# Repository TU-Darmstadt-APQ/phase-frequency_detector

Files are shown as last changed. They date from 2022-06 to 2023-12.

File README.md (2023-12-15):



Phase-Frequency Detector
=====================
This repository contains the [KiCad](https://www.kicad.org/) design files of a phase-frequency detector designed for application in optical phase-locked loops (OPLL). The detector compares a beat-note signal with a reference signal and creates an output signal proportional to the phase deviation of the beat-note from the reference. Optionally, the beat-note input can be equipped with a divider (default: 4) for a larger input-frequency range.  The module also comprises a fast analog proportional-derivative controller for high-bandwidth feedback. 

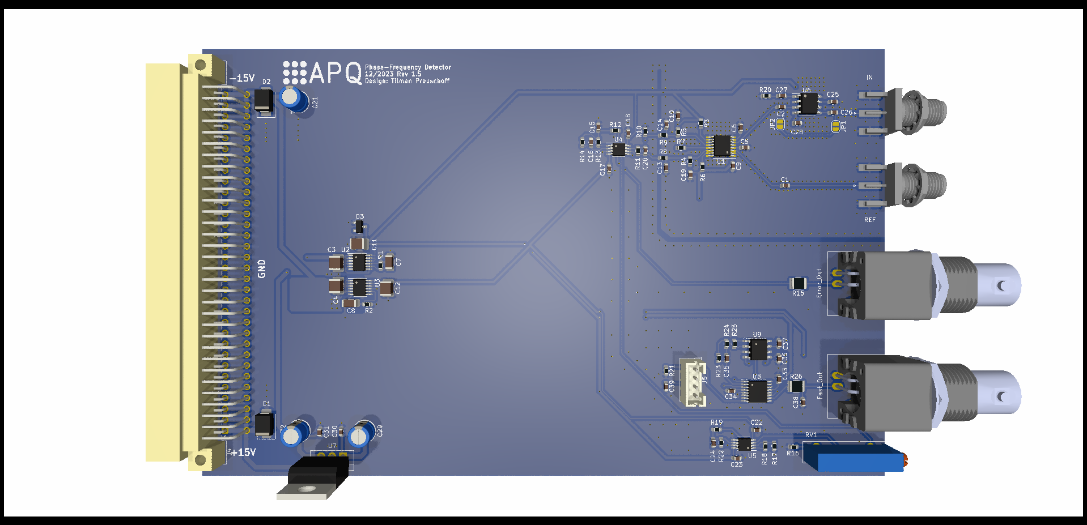
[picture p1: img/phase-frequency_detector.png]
PCB image


**Features**

- Input frequency range
  - 10 MHz to 1.3 GHz without divider
  - 500 MHz to 5.2 GHz with divider (HMC365)
- Input signal level: -10 dBm to +10 dBm
- Error signal output:
  - Bandwidth 4 MHz (2. order filter)
  - Output voltage ±1 V max. (high-Z)
- PD controller
  - Output voltage ±5 V max. (high-Z)
  - Level adjustable between 4% and 100% via frontpanel trim pot
  - Gain sign adjustable via frontpanel switch
  - Hardware adjustable corner-frequency (default: 0.8 MHz) and gain limit (default: 32 dB)

Assembly
---------------

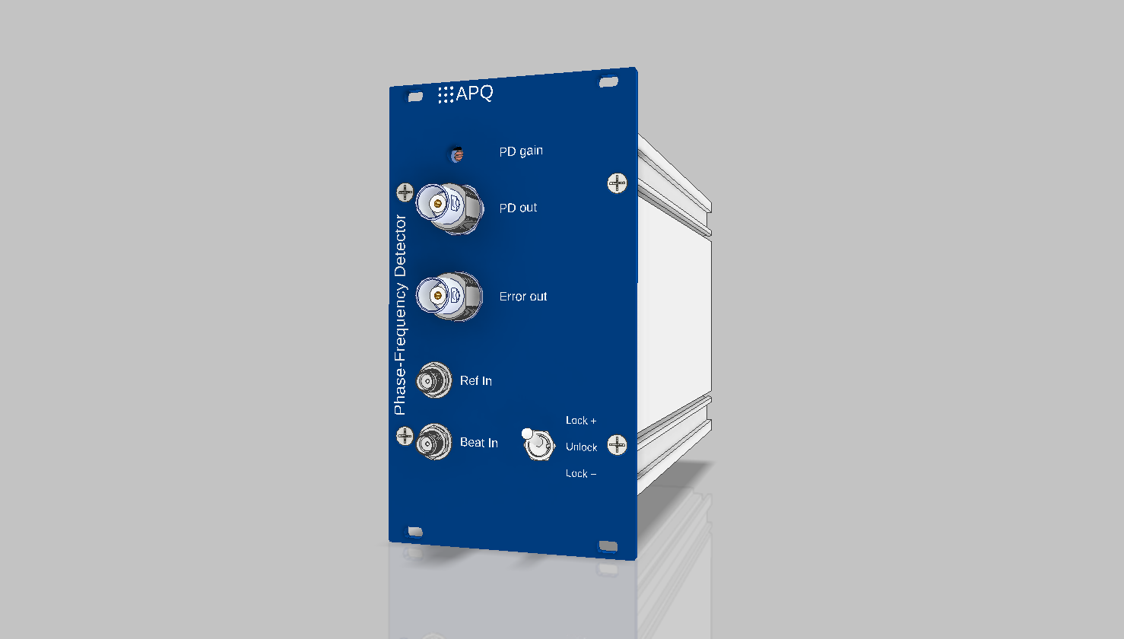
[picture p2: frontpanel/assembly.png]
case


The PCB is placed in a standard 19''-rack mount unit. Use the [switch breakout board](https://github.com/TU-Darmstadt-APQ/phase-frequency_detector_switch_breakout) for connecting the frontpanel switch of the PD controller. See `frontpanel/` folder for drawings and frontpanel artwork.

 Design Files
-------------------
The design files can be found on the [releases](../../releases) page and include the following resources:

- Schematics as a PDF
- Gerber files
- Pick & place position files
- Bill of materials as a CSV file and also as an interactive HTML version

The latest revision of those files can be found [here](../../releases/latest).

Related work
--------------------
T. Preuschoff, *Laser Technologies for Applications in Quantum Information Science*, Ph.D. thesis, TU Darmstadt, 2023, [https://tuprints.ulb.tu-darmstadt.de/23242/](https://tuprints.ulb.tu-darmstadt.de/23242/)

Requirements
----------------------
- Dual power supply
   - +15 V (0.35 A typ.)
   - \- 15 V (0.15 A typ.)
- 19-inch rack mount (e.g. [Fischer Elektronik BGT384](https://www.fischerelektronik.de/web_fischer/en_GB/cases/N05.1/19%22%20subracks/$catalogue/fischerData/PR/BGT384_180/search.xhtml))

License
-----------

This work is released under the CERN OHL v.1.2
See www.ohwr.org/licenses/cern-ohl/v1.2 or the included LICENSE file for more information.

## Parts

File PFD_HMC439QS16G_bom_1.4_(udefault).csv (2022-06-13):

Component | Quantity Per PCB | References | Value | MFN | PN | Description | Footprint | Sheetpath
1 | 4 | C13-C14 C20 C24 | 15p | Vishay / Vitramon | VJ0603A150JXBAC | Unpolarized capacitor, small symbol | C_0603_1608Metric | /
2 | 4 | C1-C2 C25-C26 | 100p | TDK | CGJ3E2C0G2A101J080AA | Unpolarized capacitor, small symbol | C_0603_1608Metric | /
3 | 1 | C16 | 150p | Vishay / Vitramon | VJ0603A151JXBAC | Unpolarized capacitor, small symbol | C_0603_1608Metric | /
4 | 1 | C15 | 560p | Vishay / Vitramon | VJ0603A561JXAAC | Unpolarized capacitor, small symbol | C_0603_1608Metric | /
5 | 6 | C5-C6 C10 C19 C27 C35 | 1n | KEMET | C0603X102K4RACAUTO | Unpolarized capacitor, small symbol | C_0603_1608Metric | /
6 | 13 | C9 C17-C18 C22-C23 C28 C30-C31 C33-C34 C36-C37 C39 | 100n | KEMET | C0603C104K5RAC3121 | Unpolarized capacitor, small symbol | C_0603_1608Metric | /
7 | 2 | C7-C8 | 100n | Murata-Electronics | GRM3195C2A104JA01D | Unpolarized capacitor, small symbol | C_1206_3216Metric | /
8 | 4 | C3-C4 C11-C12 | 10u | TDK | C3225X7R2A106K250AC | Unpolarized capacitor, small symbol | C_1210_3225Metric | /
9 | 3 | C21 C29 C32 | 100u | Panasonic | ECA-1AM101I | Polarized capacitor, small symbol | CP_Radial_D5.0mm_P2.50mm | /
10 | 1 | D3 | PMEG2010 | Nexperia | PMEG2010AET,215 | Schottky diode, cathode on pins 2 and 3 | SOT-23 | /
11 | 2 | D1-D2 | SMB | Bourns | SMBJ40CA-QH | Bidirectional transient-voltage-suppression diode | D_SMB | /
12 | 1 | J4 | C64AC | HARTING | 09221326921222 | DIN41612 connector, double row (AC), 02x32, script generated (kicad-library-utils/schlib/autogen/connector/) | DIN41612_C_2x32_Male_Horizontal_THT | /
13 | 1 | J3 | Error_Out | Linx Technologies | CONBNC002 | coaxial connector (BNC, SMA, SMB, SMC, Cinch/RCA, LEMO, ...) | BNC_Amphenol_B6252HB-NPP3G-50_Horizontal | /
14 | 1 | J6 | Fast_Out | Linx Technologies | CONREVSMA006.062-G | coaxial connector (BNC, SMA, SMB, SMC, Cinch/RCA, LEMO, ...) | BNC_Amphenol_B6252HB-NPP3G-50_Horizontal | /Fast PD regulator/
15 | 2 | J1-J2 | REF | Linx Technologies | CONREVSMA006.062-G | coaxial connector (BNC, SMA, SMB, SMC, Cinch/RCA, LEMO, ...) | SMA_Amphenol_132289_EdgeMount | /
16 | 1 | J5 | Switch |  |  | Generic connector, single row, 01x04, script generated (kicad-library-utils/schlib/autogen/connector/) | JST_PH_B4B-PH-K_1x04_P2.00mm_Vertical | /Fast PD regulator/
17 | 1 | R24 | 4.7 | ROHM Semiconductor | SDR03EZPF4R70 | Resistor, small symbol | R_0603_1608Metric | /Fast PD regulator/
18 | 3 | R6-R7 R16 | 20 | Yageo | AC0603FR-0720RL | Resistor, small symbol | R_0603_1608Metric | /
19 | 2 | R15 R26 | 49.9 | Vishay / Dale | CRCW121049R9FKEA | Resistor, small symbol | R_1210_3225Metric | /
20 | 1 | R20 | 49.9 | Panasonic | ERJ-UP3F49R9V | Resistor, small symbol | R_0603_1608Metric | /
21 | 1 | R14 | 100 | Yageo | RC0603FR-13100RL | Resistor, small symbol | R_0603_1608Metric | /
22 | 13 | R3-R5 R8-R9 R12-R13 R17-R19 R22-R23 R25 | 200 | Yageo | RC0603FR-13200RL | Resistor, small symbol | R_0603_1608Metric | /
23 | 2 | R10-R11 | 390 | Yageo | RC0603FR-13390RL | Resistor, small symbol | R_0603_1608Metric | /
24 | 1 | R21 | 10k | Panasonic | ERJ-3GEYJ103V | Resistor, small symbol | R_0603_1608Metric | /Fast PD regulator/
25 | 2 | R1-R2 | 49.9k | Panasonic | ERJ-UP3F4992V | Resistor, small symbol | R_0603_1608Metric | /
26 | 1 | RV1 | 500 | Vishay / Spectrol | M43P501KB40 | Trim-potentiometer | Potentiometer_Vishay_43_Horizontal | /Fast PD regulator/
27 | 2 | U4-U5 | ADA4896-2ARMZ | Analog Devices | ADA4896-2ARMZ | 1 nV/√Hz, Low Power,Rail-to-Rail Output Amplifier | MSOP-8_3x3mm_P0.65mm_mod | /
28 | 1 | U8 | ADG1613 | Analog Devices | ADG1613BRUZ |  | TSSOP-16_4.4x5mm_P0.65mm | /Fast PD regulator/
29 | 1 | U7 | L7808 | STMicroelectronics | L7808ABV-DG | Positive 1.5A 35V Linear Regulator, Fixed Output 8V, TO-220/TO-263/TO-252 | TO-220-3_Vertical | /
30 | 1 | U2 | LT3045EMSE | Analog Devices | LT3045EMSE#PBF | 20V, 500mA, Ultralow Noise, Ultrahigh PSRR Linear Regulator, MSOP Package | MSOP-12-1EP_3x4mm_P0.65mm_EP1.65x2.85mm | /
31 | 1 | U3 | LT3094EMSE | Analog Devices | LT3094EMSE#PBF | –20V, 500mA, Ultralow Noise, Ultrahigh PSRR Negative Linear Regulator, MSOP Package | MSOP-12-1EP_3x4mm_P0.65mm_EP1.65x2.85mm | /
32 | 1 | U9 | LTC6228xS8 | Analog Devices | LTC6228IS8#PBF | Low Distortion Rail-to-Rail Output Op Amp with Shutdown, SO-8 | SO-8_3.9x4.9mm_P1.27mm | /Fast PD regulator/
Component Groups: | 36
Component Count: | 86
Fitted Components: | 81
Number of PCBs: | 1
Total components: | 81
Schematic Version: | 1.4
Schematic Date: | 2022-01-25
PCB Variant: | udefault
BoM Date: | 13.06.2022 10:36:48
Schematic Source: | PFD_HMC439QS16G.kicad_sch
KiCad Version: | Eeschema (6.0.1)

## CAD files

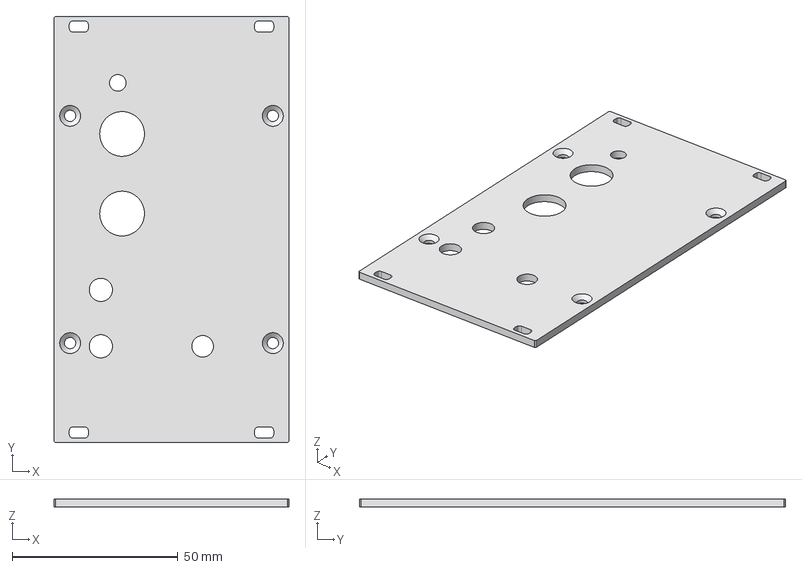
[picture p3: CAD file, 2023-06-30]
frontpanel/Fischer_TFP.stp
70.8 x 128.4 x 2.50 mm

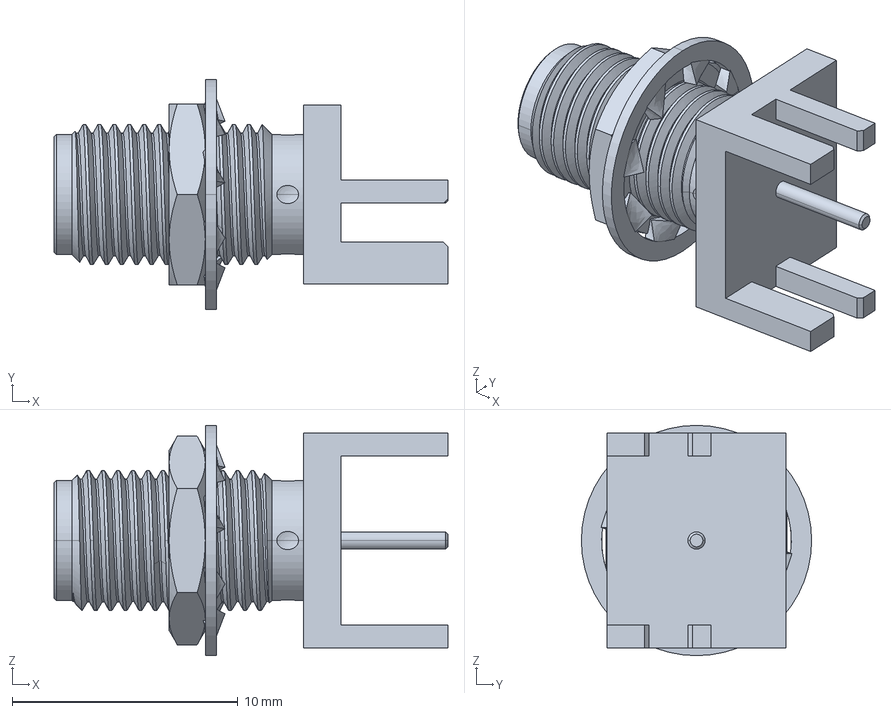
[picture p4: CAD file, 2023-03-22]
KiCad/3D-models/132289.stp
17.4 x 10.2 x 10.2 mm

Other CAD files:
frontpanel/OldVersions/Fischer_TFP.0009.dwg
frontpanel/OldVersions/Fischer_TFP.0016.dwg
frontpanel/Fischer_TFP.dwg
frontpanel/Fischer_TFP.ipt
frontpanel/OldVersions/Fischer_TFP.0034.ipt
frontpanel/assembly/132289.iam
frontpanel/assembly/A203SYCQ04.ipt
frontpanel/assembly/COMPOUND.ipt
frontpanel/assembly/CONBNC002.iam
frontpanel/assembly/Fischer HB.ipt
frontpanel/assembly/KN1.ipt
frontpanel/assembly/OldVersions/PFD.0014.iam
frontpanel/assembly/PFD.iam
frontpanel/assembly/Potentiometer_Bourns_3005_Horizontal.iam
frontpanel/assembly/SOLID.ipt
frontpanel/assembly/SOLID_1.ipt
frontpanel/assembly/phase-frequency_detector PCB.ipt
frontpanel/assembly/phase-frequency_detector.iam

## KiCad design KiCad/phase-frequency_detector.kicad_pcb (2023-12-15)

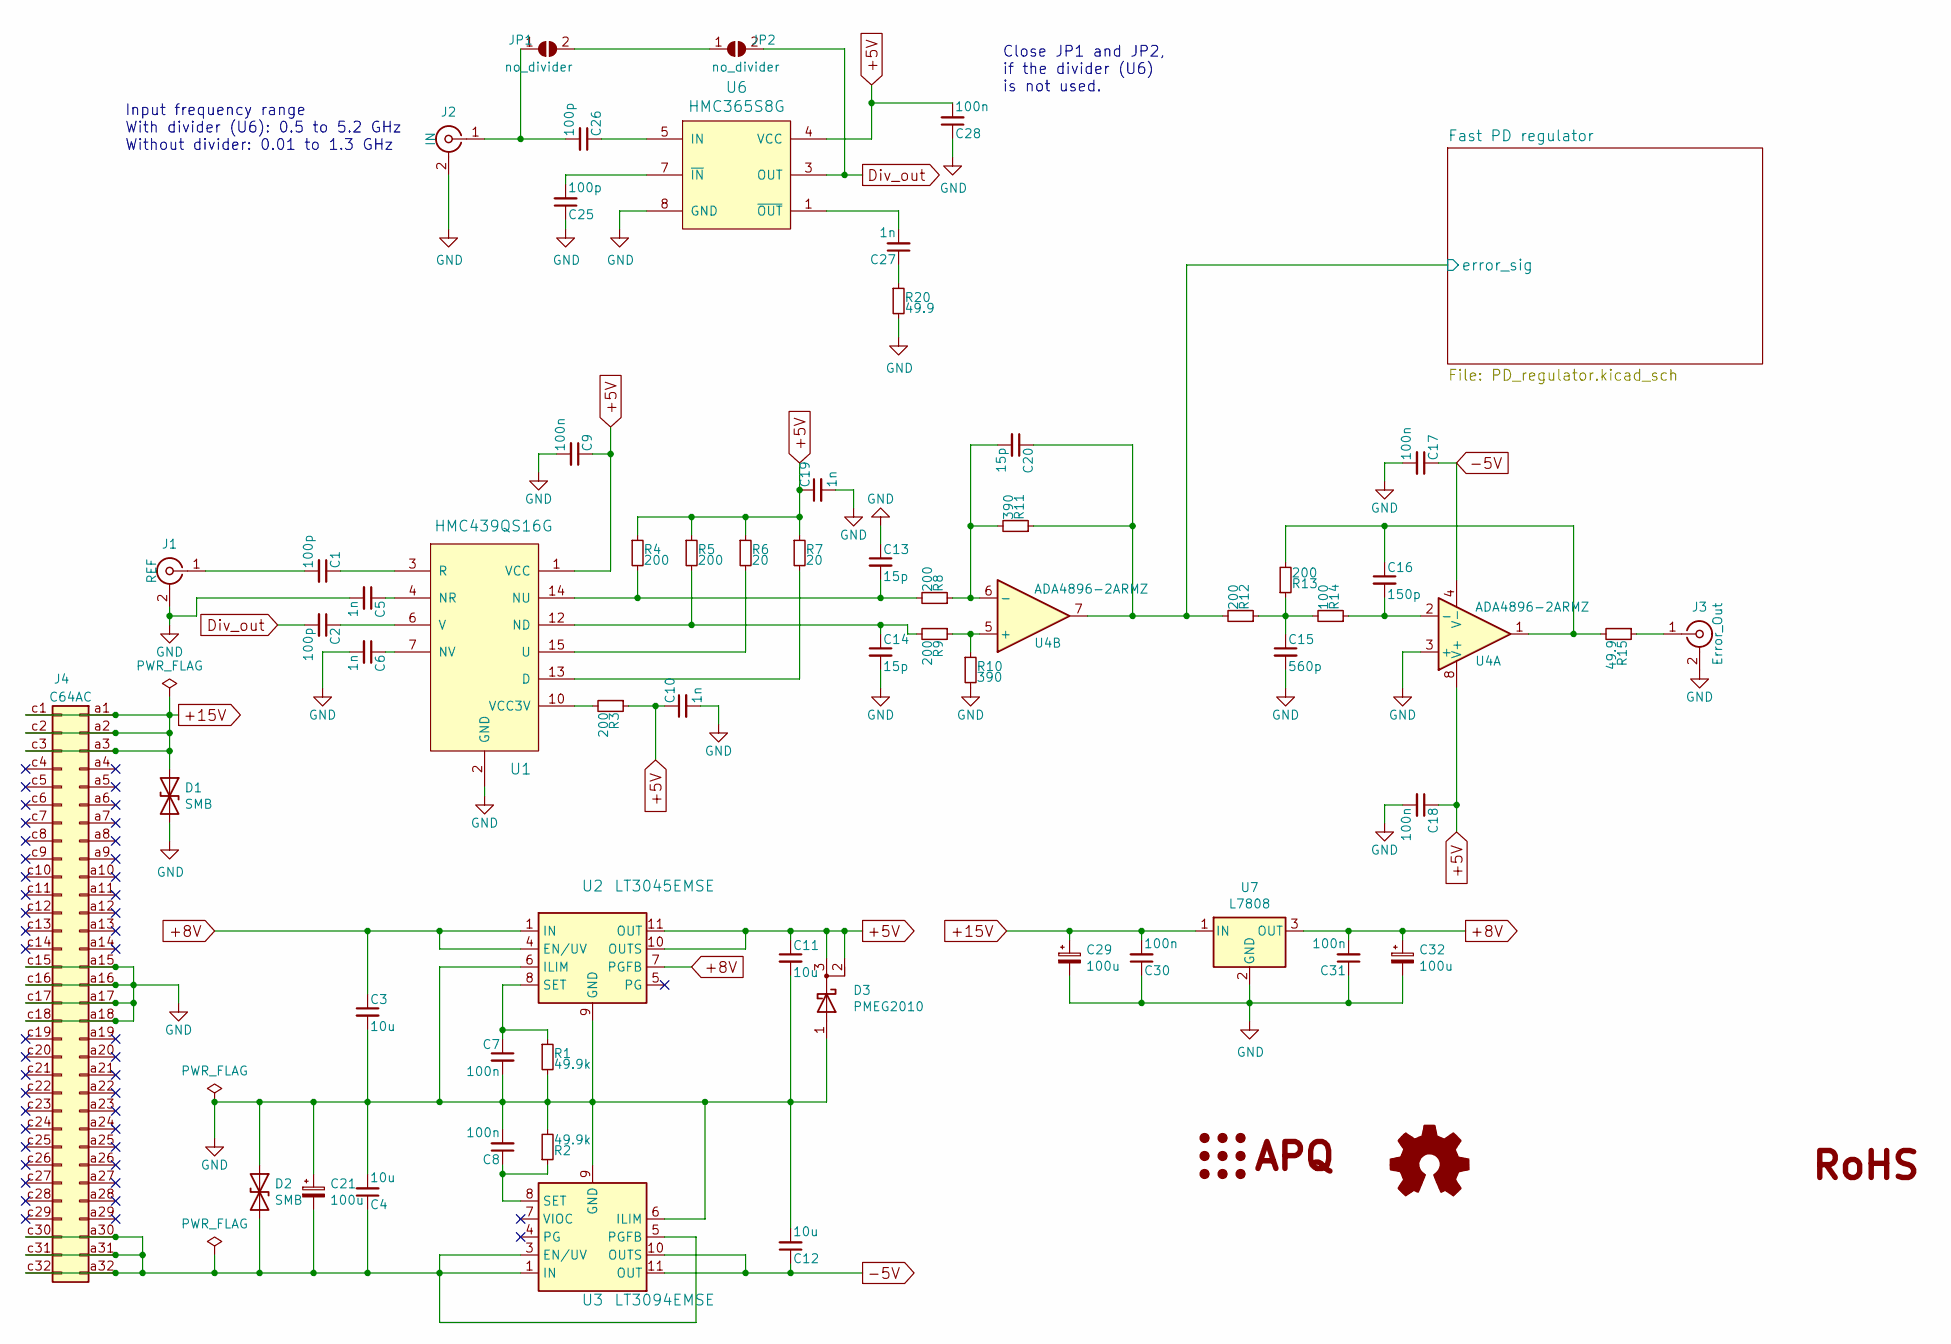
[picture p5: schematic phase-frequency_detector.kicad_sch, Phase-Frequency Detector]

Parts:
C1, C2, C25, C26: 100p; C_0603_1608Metric
C3, C4, C11, C12: 10u; C_1210_3225Metric
C5, C6, C10, C19, C27: 1n; C_0603_1608Metric
C7, C8: 100n; C_1206_3216Metric
C9, C17, C18, C28, C30, C31: 100n; C_0603_1608Metric
C13, C14, C20: 15p; C_0603_1608Metric
C15: 560p; C_0603_1608Metric
C16: 150p; C_0603_1608Metric
C21, C29, C32: 100u; CP_Radial_D5.0mm_P2.50mm
D1, D2: SMB; D_SMB
D3: PMEG2010; SOT-23
J1: REF; SMA_Amphenol_132289_EdgeMount
J2: IN; SMA_Amphenol_132289_EdgeMount
J3: Error_Out; BNC_Amphenol_B6252HB-NPP3G-50_Horizontal
J4: C64AC; DIN41612_C_2x32_Male_Horizontal_THT
JP1, JP2: no_divider; SolderJumper-2_P1.3mm_Open_RoundedPad1.0x1.5mm
LOGO1: Logo_APQ; APQ-Logo
LOGO2: Logo_Open_Hardware_Small; OSHW-Logo_5.7x6mm_SilkScreen
LOGO3: Logo_ROHS; RoHS-Logo_6mm_SilkScreen
R1, R2: 49.9k; R_0603_1608Metric
R3, R4, R5, R8, R9, R12, R13: 200; R_0603_1608Metric
R6, R7: 20; R_0603_1608Metric
R10, R11: 390; R_0603_1608Metric
R14: 100; R_0603_1608Metric
R15: 49.9; R_1210_3225Metric
R20: 49.9; R_0603_1608Metric
U1: HMC439QS16G; QSOP-16_3.9x4.9mm_P0.635mm_EP_2.3mmx1.75mm_DNF
U2: LT3045EMSE; MSOP-12-1EP_3x4mm_P0.65mm_EP1.65x2.85mm
U3: LT3094EMSE; MSOP-12-1EP_3x4mm_P0.65mm_EP1.65x2.85mm
U4: ADA4896-2ARMZ; MSOP-8_3x3mm_P0.65mm_mod
U6: HMC365S8G; SOIC-8-1EP_3.9x4.9mm_P1.27mm_EP2.41x3.81mm
U7: L7808; TO-220-3_Vertical

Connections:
+5V: C9.1, C10.1, C11.1, C18.1, C19.1, C28.2, D3.2 (K), D3.3 (K), R3.1, R4.1, R5.1, R6.1, R7.1, U1.1 (VCC), U2.10 (OUTS), U2.11 (OUT), U2.12 (OUT), U4.8 (V+), U6.4 (VCC); also elsewhere on the board
+8V: C3.1, C31.2, C32.1, U2.1 (IN), U2.2 (IN), U2.3 (IN), U2.4 (EN/UV), U2.7 (PGFB), U7.3 (OUT)
+15V: C29.1, C30.2, D1.1 (A1), J4.a1, J4.a2, J4.a3, J4.c1, J4.c2, J4.c3, U7.1 (IN)
-5V: C12.1, C17.1, U3.10 (OUTS), U3.11 (OUT), U3.12 (OUT), U4.4 (V-); also elsewhere on the board
/Fast PD regulator/error_sig: C20.1, R11.1, R12.2, U4.7; also elsewhere on the board
Div_out: C2.2, JP2.2 (B), U6.3 (OUT)
GND: C3.2, C4.2, C5.2, C6.2, C7.2, C8.2, C9.2, C10.2, C11.2, C12.2, C13.1, C14.2, C15.2, C17.2, C18.2, C19.2, C21.1, C25.1, C28.1, C29.2, C30.1, C31.1, C32.2, D1.2 (A2), D2.1 (A1), D3.1 (A), J1.2 (Ext), J2.2 (Ext), J3.2 (Ext), J4.a15, J4.a16, J4.a17, J4.a18, J4.c15, J4.c16, J4.c17, J4.c18, R1.2, R2.2, R10.2, R20.2, U1.2 (GND), U1.5 (GND), U1.8 (GND), U1.9 (GND), U1.11 (GND), U1.16 (GND), U1.17 (GND), U2.6 (ILIM), U2.9 (GND), U2.13 (GND), U3.6 (ILIM), U3.9 (GND), U4.3 (+), U6.8 (GND), U6.9 (GND), U7.2 (GND); also elsewhere on the board
unnamed: C15.1, R12.1, R13.1, R14.2
unnamed: C16.1, R13.2, R15.2, U4.1
unnamed: C27.1, R20.1
unnamed: C4.1, C21.2, D2.2 (A2), J4.a30, J4.a31, J4.a32, J4.c30, J4.c31, J4.c32, U3.1 (IN), U3.2 (IN), U3.3 (EN/UV), U3.5 (PGFB), U3.13 (IN)
unnamed: C1.2, J1.1 (In)
unnamed: C26.2, J2.1 (In), JP1.1 (A)
unnamed: J3.1 (In), R15.1
unnamed: JP1.2 (B), JP2.1 (A)
unnamed: R7.2, U1.13 (D)
unnamed: C14.1, R5.2, R9.2, U1.12 (ND)
unnamed: C5.1, U1.4 (NR)
unnamed: C13.2, R4.2, R8.2, U1.14 (NU)
unnamed: C6.1, U1.7 (NV)
unnamed: C1.1, U1.3 (R)
unnamed: R6.2, U1.15 (U)
unnamed: C2.1, U1.6 (V)
unnamed: R3.2, U1.10 (VCC3V)
unnamed: C7.1, R1.1, U2.8 (SET)
unnamed: C8.1, R2.1, U3.8 (SET)
unnamed: C16.2, R14.1, U4.2 (-)
unnamed: R9.1, R10.1, U4.5 (+)
unnamed: C20.2, R8.1, R11.2, U4.6 (-)
unnamed: C26.1, U6.5 (IN)
unnamed: C25.2, U6.7 (~IN)
unnamed: C27.2, U6.1 (~OUT)

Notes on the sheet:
Input frequency range With divider (U6): 0.5 to 5.2 GHz Without divider: 0.01 to 1.3 GHz
Close JP1 and JP2, if the divider (U6) is not used.

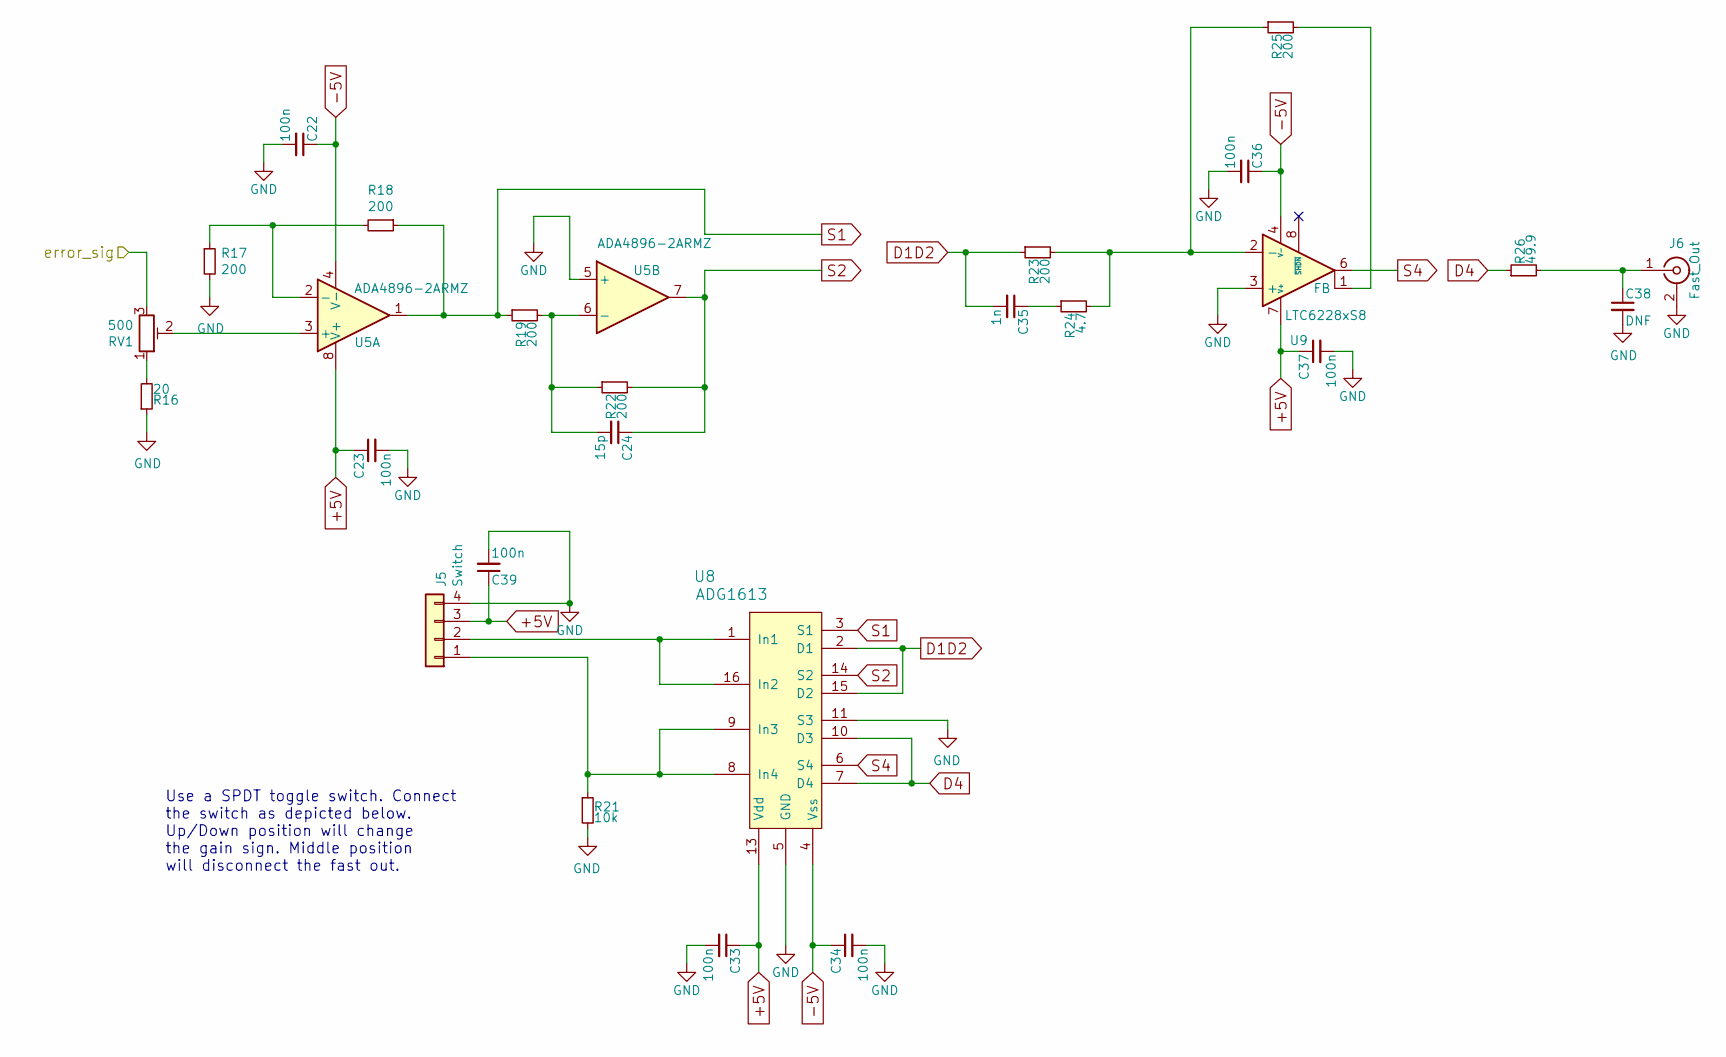
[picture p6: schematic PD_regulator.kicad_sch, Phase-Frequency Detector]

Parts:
C22, C23, C33, C34, C36, C37, C39: 100n; C_0603_1608Metric
C24: 15p; C_0603_1608Metric
C35: 1n; C_0603_1608Metric
C38: DNF; C_0603_1608Metric
J5: Switch; JST_PH_B4B-PH-K_1x04_P2.00mm_Vertical
J6: Fast_Out; BNC_Amphenol_B6252HB-NPP3G-50_Horizontal
R16: 20; R_0603_1608Metric
R17, R18, R19, R22, R23, R25: 200; R_0603_1608Metric
R21: 10k; R_0603_1608Metric
R24: 4.7; R_0603_1608Metric
R26: 49.9; R_1210_3225Metric
RV1: 500; Potentiometer_Vishay_43_Horizontal
U5: ADA4896-2ARMZ; MSOP-8_3x3mm_P0.65mm_mod
U8: ADG1613; TSSOP-16_4.4x5mm_P0.65mm
U9: LTC6228xS8; SO-8_3.9x4.9mm_P1.27mm

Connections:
+5V: C23.1, C33.1, C37.1, C39.1, J5.3, U5.8 (V+), U8.13 (Vdd), U9.7 (V+); also elsewhere on the board
-5V: C22.1, C34.1, C36.1, U5.4 (V-), U8.4 (Vss), U9.4 (V-), U9.5 (V-); also elsewhere on the board
/Fast PD regulator/error_sig: RV1.3; also elsewhere on the board
D1D2: C35.2, R23.1, U8.2 (D1), U8.15 (D2)
D4: R26.1, U8.7 (D4), U8.10 (D3)
GND: C22.2, C23.2, C33.2, C34.2, C36.2, C37.2, C38.2, C39.2, J5.4, J6.2 (Ext), R16.1, R17.2, R21.2, U5.5 (+), U8.5 (GND), U8.11 (S3), U9.3 (+); also elsewhere on the board
unnamed: C35.1, R24.1
unnamed: J5.1, R21.1, U8.8 (In4), U8.9 (In3)
unnamed: J5.2, U8.1 (In1), U8.16 (In2)
unnamed: C38.1, J6.1 (In), R26.2
unnamed: R16.2, RV1.1
unnamed: RV1.2, U5.3 (+)
unnamed: R17.1, R18.2, U5.2 (-)
unnamed: C24.2, R19.2, R22.1, U5.6 (-)
unnamed: R23.2, R24.2, R25.1, U9.2 (-)
unnamed: R25.2, U9.1 (FB)
S1: R18.1, R19.1, U5.1, U8.3 (S1)
S2: C24.1, R22.2, U5.7, U8.14 (S2)
S4: U8.6 (S4), U9.6

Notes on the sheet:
Use a SPDT toggle switch. Connect the switch as depicted below. Up/Down position will change the gain sign. Middle position will disconnect the fast out.

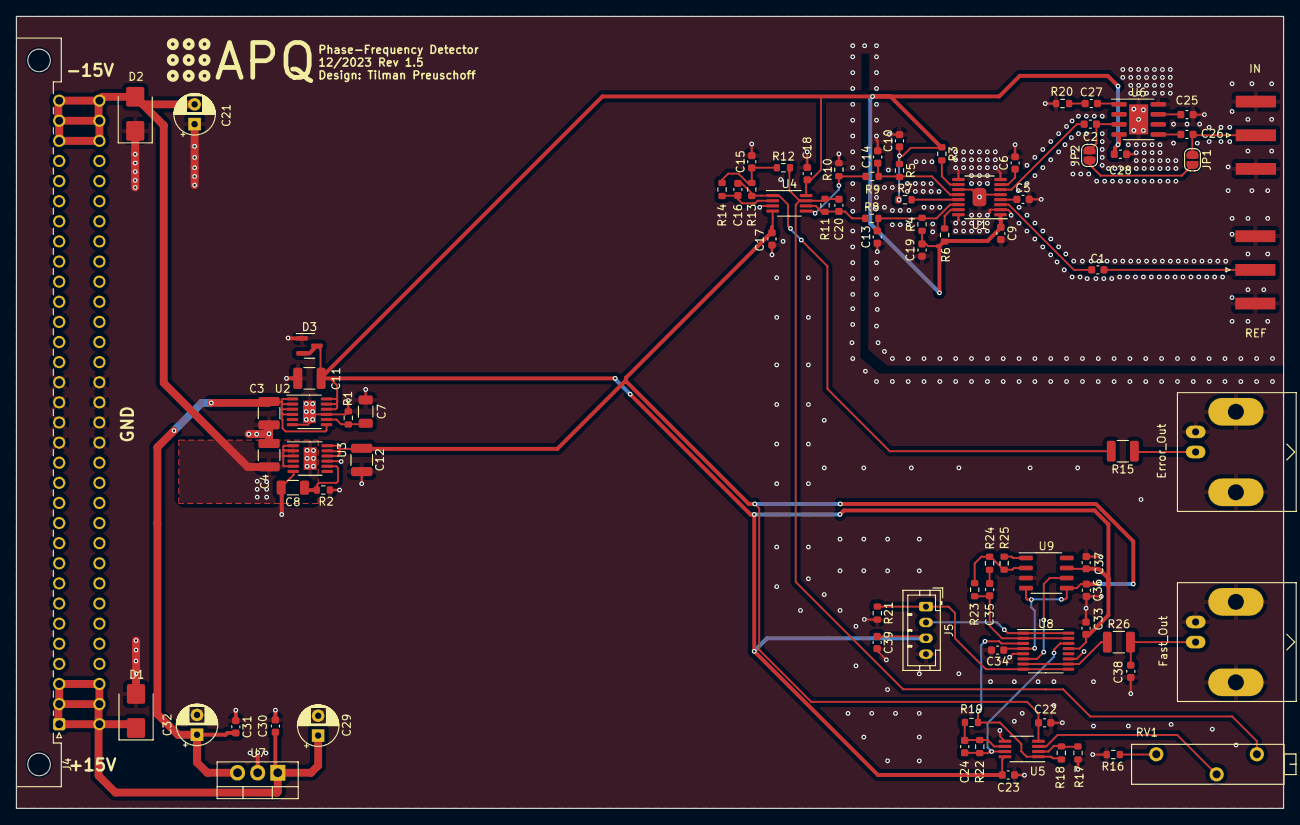
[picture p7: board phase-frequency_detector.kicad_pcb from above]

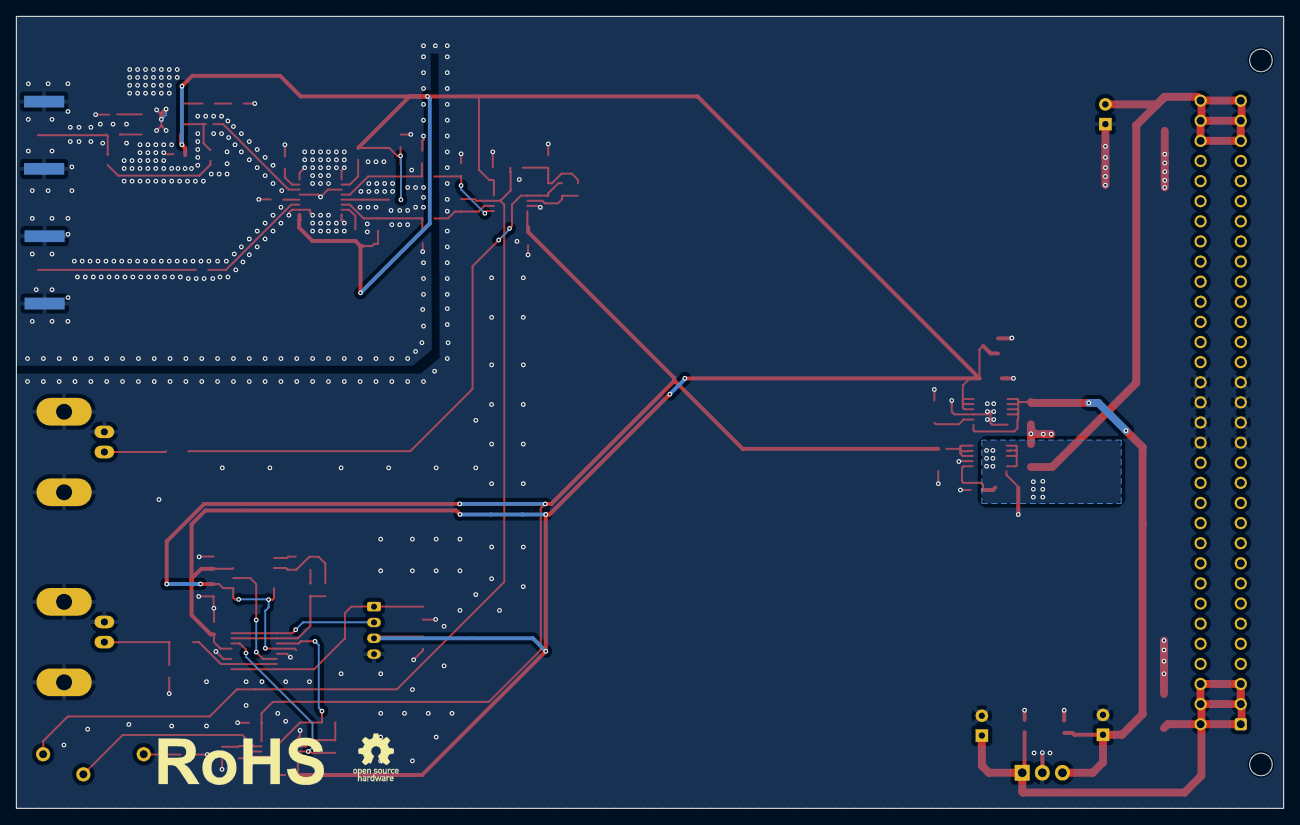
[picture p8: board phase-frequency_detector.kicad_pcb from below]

Board: 2 copper layers, 160.0 x 100.0 mm, 89 parts (2 on the bottom side), 47 nets.

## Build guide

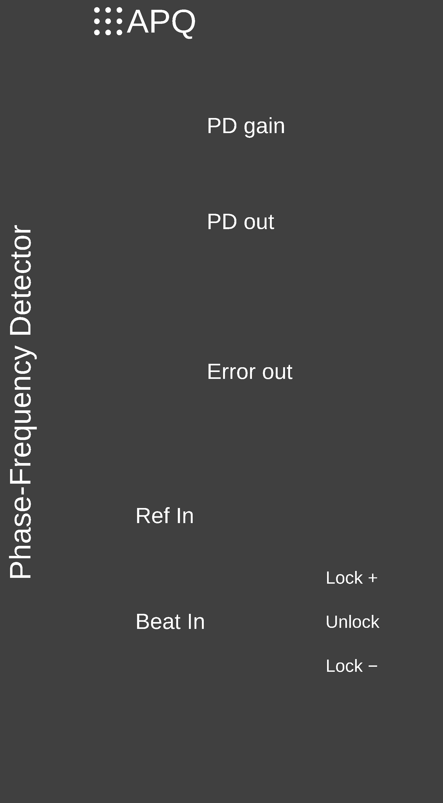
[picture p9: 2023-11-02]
frontpanel/print.png

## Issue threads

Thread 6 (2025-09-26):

Different divider values for the prescale

MMittenbuehler, 2025-09-26:
Optionally, a HMC365 chip can be soldered onto the pcb to perform a division by 4. First up, we should improve the documentation on how this should be implemented in practice, i.e. either solder the chip or connect the solder bridges.

We would need a division by 8 for our experiment so the issue came up of selecting an external prescaler. During my search, I stumbled on the HMC363S8GE which has the exact same layout as the HMC365 but performs a division by 8. We should test whether this works as expected. If this is the case, we could also check the HMC361 and HMC362.

One issue could be that the 363 only outputs -6dBm (-9dBm minimum), however, this is still above the minimum requirement of -10dBm by the phase frequency detector (HMC439), assuming the transmission line has low losses.

@PatrickBaus what do you think? Am I missing something here or could this be a simple option?

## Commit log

2020-11-23 Rev 1.1
    [PFD_HMC439QS16G-2020-05-23-23-10-47.sch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]
2020-12-04 Reverse Trimpot. Update gerber files
    [PFD_HMC439QS16G-B_Cu.gbr, PFD_HMC439QS16G-B_Fab.gbr, PFD_HMC439QS16G-B_Mask.gbr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]
2021-03-18 Rev. 1.2
    -Divide input signal by 4 using HMC365
    -Change board layout to standard eurocard
    -Minor changes to 'Fast Out': Optional AC-coupling, optional gain
    [PFD_HMC439QS16G-B_Cu.gbr, PFD_HMC439QS16G-B_Fab.gbr, PFD_HMC439QS16G-B_Mask.gbr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]
2021-03-19 Add gain of 2 and increase bandwidth at U4B
    [PFD_HMC439QS16G.sch]
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2021-03-21 Update gerber files
    [PFD_HMC439QS16G-B_Cu.gbr, PFD_HMC439QS16G-B_Fab.gbr, PFD_HMC439QS16G-B_Mask.gbr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]
2022-01-17 First draft: fast PD regulator
    [PD_regulator.sch, PFD_HMC439QS16G.sch]
2022-01-18 Fast PD second draft
    [PD_regulator.sch, PFD_HMC439QS16G.kicad_pcb, PFD_HMC439QS16G.sch]
2022-01-18 Add fast PD regulator
    [PD_regulator.sch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]
2022-01-18 Add drawing and comment for switch connection
    [PD_regulator.sch]
2022-01-24 Add 'no divider' option and clamping diode / Update to KiCad 6
    [PD_regulator.kicad_sch, PFD_HMC439QS16G.kicad_pcb, PFD_HMC439QS16G.kicad_sch]
2022-01-25 Fix HMC365 and ADG1413 symbols. Update gerber files.
    [PD_regulator.kicad_sch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]
2022-01-25 Remove additional KiCad 5 gerber files
    [PFD_HMC439QS16G-B_SilkS.gbr, PFD_HMC439QS16G-F_SilkS.gbr]
2022-01-27 Remove KiCad 5 files and ignore backup files
    [PD_regulator.sch, PFD_HMC439QS16G.sch]
2022-01-27 Update BOM / fix some fottprints
    [PD_regulator.kicad_sch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]
2022-06-09 Updated BOM with new parts
    [PD_regulator.kicad_sch, PFD_HMC439QS16G.kicad_sch]
2022-06-13 Update BOM.ini. Generate BOM.
    [PFD_HMC439QS16G_bom_1.4_(udefault).csv]
2023-03-22 Update BOM
    [PD_regulator.kicad_sch, PFD_HMC439QS16G.kicad_pcb, PFD_HMC439QS16G.kicad_sch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]
2023-03-22 Rename project files
    [phase-frequency_detector.kicad_pcb, phase-frequency_detector.kicad_sch, phase-frequency_detector_bom_1.4.csv]
2023-03-22 Add comments and fix custom footprint lib.
    [phase-frequency_detector.kicad_sch]
2023-03-22 Remove solder paste from DNF footprints.
    [PD_regulator.kicad_sch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]
2023-03-22 Add 3D models
    [132289.stp, phase-frequency_detector.kicad_pcb, phase-frequency_detector_bom_1.4.1.csv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]
2023-06-16 Create frontpanel design
    [Fischer HB.ipt, Fischer_TFP.0008.dwg, Fischer_TFP.0017.ipt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]
2023-06-16 Add assembly instructions
    [phase-frequency_detector-B_Cu.gbr, phase-frequency_detector-B_Fab.gbr, phase-frequency_detector-B_Mask.gbr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]
2023-06-16 Replace ADG1613 with ADG1413 due to better availability
    [PD_regulator.kicad_sch, phase-frequency_detector.kicad_sch]
2023-06-16 Remove obsolete gerber files
    [PFD_HMC439QS16G-B_Cu.gbr, PFD_HMC439QS16G-B_Fab.gbr, PFD_HMC439QS16G-B_Mask.gbr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]
2023-06-23 Create switch breakout board
    [Fischer_TFP.0017.ipt, Fischer_TFP.0019.ipt, Fischer_TFP.ipt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]
2023-06-23 Replaced swtich_breakout with submodule
    [switch_breakout-B_Cu.gbr, switch_breakout-B_Fab.gbr, switch_breakout-B_Mask.gbr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]
2023-06-23 Update frontpanel
    [132289.iam, A203SYCQ04.ipt, COMPOUND.ipt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]
2023-06-23 Correct PN for Harting and BNC connectors
    [PD_regulator.kicad_sch, phase-frequency_detector.kicad_sch, phase-frequency_detector_bom_1.4.1.csv]
2023-06-28 Update frontpanel drawing
    [Fischer_TFP.0008.dwg, Fischer_TFP.0009.dwg, Fischer_TFP.dwg]
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2023-06-30 Add case PN
    [Fischer_TFP.0009.dwg, Fischer_TFP.0013.dwg, Fischer_TFP.0026.ipt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]
2023-06-30 Add frontpanel manufacturing information
    [Fischer_TFP.0013.dwg, Fischer_TFP.0015.dwg, Fischer_TFP.dwg]
2023-08-08 Update assembly model
    [PFD.0008.iam, PFD.0009.iam, PFD.iam]
2023-11-02 Add README and LICENSE
    [Fischer_TFP.0028.ipt, Fischer_TFP.0034.ipt, Fischer_TFP.ipt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]
2023-11-02 Fix ADG1413/1613 symbol
    [PD_regulator.kicad_sch, phase-frequency_detector.kicad_sch]
2023-11-03 Updated to KiCad 7 Added CI pipeline Fixed trailing whitespaces of MFN and PN labels Fixed ERC/DRC errors
    [PD_regulator.kicad_sch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]
2023-11-05 Fixed logos on schematic
    [phase-frequency_detector.kicad_sch]
2023-11-06 Bump switch_breakout from `e1719e6` to `3b2b977`
    Bumps [switch_breakout](https://github.com/TU-Darmstadt-APQ/phase-frequency_detector_switch_breakout) from `e1719e6` to `3b2b977`.
    - [Release notes](https://github.com/TU-Darmstadt-APQ/phase-frequency_detector_switch_breakout/releases)
    - [Commits](https://github.com/TU-Darmstadt-APQ/phase-frequency_detector_switch_breakout/compare/e1719e65053c7a6c27b33b2e67abfd7177f710e9...3b2b97732aaf6d5b28b69c52752f8d6397ca5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)
    ---
    updated-dependencies:
    - dependency-name: switch_breakout
    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
2023-11-07 Update LT3045/LT3094 symbols
    [phase-frequency_detector.kicad_pcb, phase-frequency_detector.kicad_sch]
2023-11-08 Add model for Fischer KN1
    [KN1.ipt]
2023-12-15 Move BNC connectors to be flush with edge-mount SMA connectors
    [PD_regulator.kicad_sch, phase-frequency_detector.kicad_pcb, phase-frequency_detector.kicad_sch]
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2025-08-07 Bump switch_breakout from `e3cf733` to `a8cd211`
    Bumps [switch_breakout](https://github.com/TU-Darmstadt-APQ/phase-frequency_detector_switch_breakout) from `e3cf733` to `a8cd211`.
    - [Commits](https://github.com/TU-Darmstadt-APQ/phase-frequency_detector_switch_breakout/compare/e3cf733fa28ee9e9b3a202e3d92bd92609e3e065...a8cd21180e583919de076987f8dedbac1473b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)
    dependency-version: a8cd21180e583919de076987f8dedbac1473b8f9
    dependency-type: direct:production
    ...
    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
2025-08-12 Bump switch_breakout from `a8cd211` to `b494cff`
    Bumps [switch_breakout](https://github.com/TU-Darmstadt-APQ/phase-frequency_detector_switch_breakout) from `a8cd211` to `b494cff`.
    - [Commits](https://github.com/TU-Darmstadt-APQ/phase-frequency_detector_switch_breakout/compare/a8cd21180e583919de076987f8dedbac1473b8f9...b494cffa423c276e74c238047f78d96448878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)
    dependency-version: b494cffa423c276e74c238047f78d964488781c3
    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
